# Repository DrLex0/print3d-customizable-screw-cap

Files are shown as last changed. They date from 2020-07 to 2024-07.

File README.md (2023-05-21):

# Customizable Screw Cap
*3D printable cap or lid with screw thread for tubes and round boxes*

### License
[Creative Commons - Attribution](https://creativecommons.org/licenses/by/4.0/)

### Attribution
This uses the `screw_extrude` function from “customizable round box with threaded lid” by FaberUnserzeit a.k.a. Philipp Klostermann ([Thingiverse thing:1648580](https://www.thingiverse.com/thing:1648580)).

### Gallery

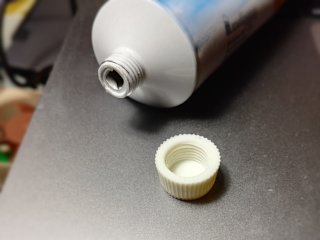
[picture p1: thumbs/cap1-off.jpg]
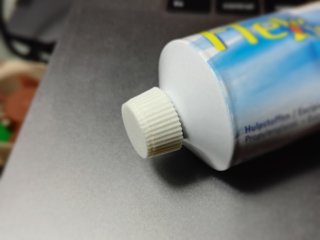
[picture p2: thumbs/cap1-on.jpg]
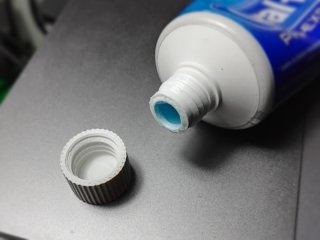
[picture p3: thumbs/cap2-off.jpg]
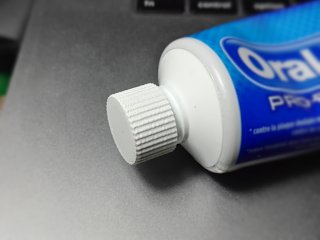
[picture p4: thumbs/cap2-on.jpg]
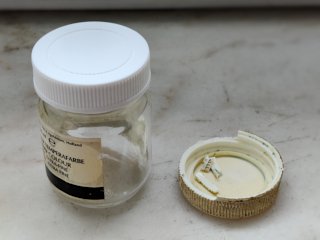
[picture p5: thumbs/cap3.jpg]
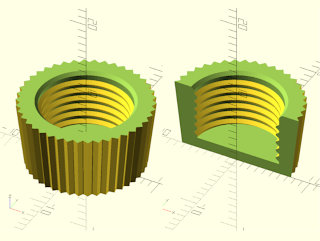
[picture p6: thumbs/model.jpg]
OpenSCAD Preview
[🔎](images/cap1-off.jpg) [🔎](images/cap1-on.jpg) [🔎](images/cap2-off.jpg) [🔎](images/cap2-on.jpg) [🔎](images/cap3.jpg) [🔎](images/model.jpg)

## Description and Instructions

This is an OpenSCAD Customizer for generating screw caps for tubes (toothpaste, gel, …), or lids for round boxes. Some possible use cases:
* You lost the cap for the tube or box,
* The original cap broke or your dog chewed on it,
* The original cap is large and bulky, and you want something more elegant to carry in a travel bag.

To generate a cap or lid for your particular needs, first do some accurate measurements on the thing the cap will need to fit on. A calliper is pretty much essential for this, although you might also get somewhere with a simple ruler and some good eyeballing. The more accurate the values, the better the chance your first printed cap will be a perfect fit and you won't need trial-and-error.

Measure these dimensions:
1. The outer diameter of the screw thread.
2. The pitch of the screw thread. It is better to measure as many turns together as possible, and then divide the measured distance by this number of turns. I usually measure with both the inside and outside prongs of the calliper to verify that I'm not making any error in the measurement.
3. The length of the threaded end that must be covered by the cap. Some tubes have a thicker ring at the base of the thread, you should not include this in the measurement.

Once you have those measurements, open the `.scad` file in [OpenSCAD](https://www.openscad.org/) and **[use the OpenSCAD Customizer](https://www.dr-lex.be/3d-printing/customizer.html)** to enter the values and generate the final STL file. Next to the above parameters, there are many other things that can be customised. The most important parameter is the spacing: if the cap is too sloppy then increase this value, if it is too tight, then lower it. For me, a spacing of 0.40 mm works well.
For certain lids it may be necessary to increase the gap between threads. The gap is expressed as a fraction of the pitch and the higher the value, the more the thread shape will be squished. High gap values may be more difficult to print cleanly.

Other parameters define the overall shape of the cap or lid. You can opt to give the cap a ribbed (knurled) outside for better grip.

### Print Settings I've used

For finer screw threads, a layer height of 0.1 mm is recommended. For coarser threads, 0.15 mm may suffice, and for big lids 0.2 mm may even be OK. The caps shown in the photos were printed with 3 perimeters. I used ABS, but in general PETG is probably the best material choice because of its toughness and resilience against chemicals. Of course PLA will also work fine in many cases.

## Example files

The `examples` folder contains some pre-rendered models of the presets.

- `Flexium` is for a metal tube of anti-inflammatory gel, and might fit similar tubes.
- `medicalBottle` fits many of the typical bottles used in medicine. The `polished` model has been tweaked in Blender to look nicer. (Should probably be used with an extra seal or wad.)
- `OralB-75ml` fits a plastic toothpaste tube and might also fit similar tubes.
- `Talens-paint-50ml` fits a small glass jar of paint. This also has a `polished` model that looks more like the original.

## License: if you want to sell prints

The OpenSCAD customizer is released under a [Creative Commons - Attribution](https://creativecommons.org/licenses/by/4.0/) license and so is every 3D model generated by it. In a nutshell, my interpretation of this license is that you can sell prints of models generated with this OpenSCAD customizer under the following conditions:

1. On webpages where you sell these models or display photos of them, or include them in a video: visibly add an *attribution* message that links back to this GitHub page, like:<br>
   “3D models generated with [Customizable Screw Cap by DrLex](https://github.com/DrLex0/print3d-customizable-screw-cap), released under *Creative Commons - Attribution* license.”
2. With every physical sold object, include a similar attribution message printed on a piece of paper that also contains the GitHub page URL. For your convenience, ready-to-print PDF files with attribution cards are provided in this repository.

If you comply with the above conditions, *you do not need to ask permission* to sell models based on this customizer. *You do not need to share profits,* the attribution is all that is required. Of course you are free to show gratitude by sharing whatever you want, for instance through the [donation options on my website](https://www.dr-lex.be/about/#contact).

## Updates

### 2020/07/02
First published.

### 2022/04/08
Added thread gap and increased limits on some parameters.

### 2023/01/05
Added option for extra unthreaded space on inside of cap, and allow bottom to be 0 to generate an open threaded tube.

### 2023/05/07
Added option for hole in the cap.

## Tags
`customizable`, `customizer`, `openscad`, `tube`, `box`, `lid`, `cap`, `thread`

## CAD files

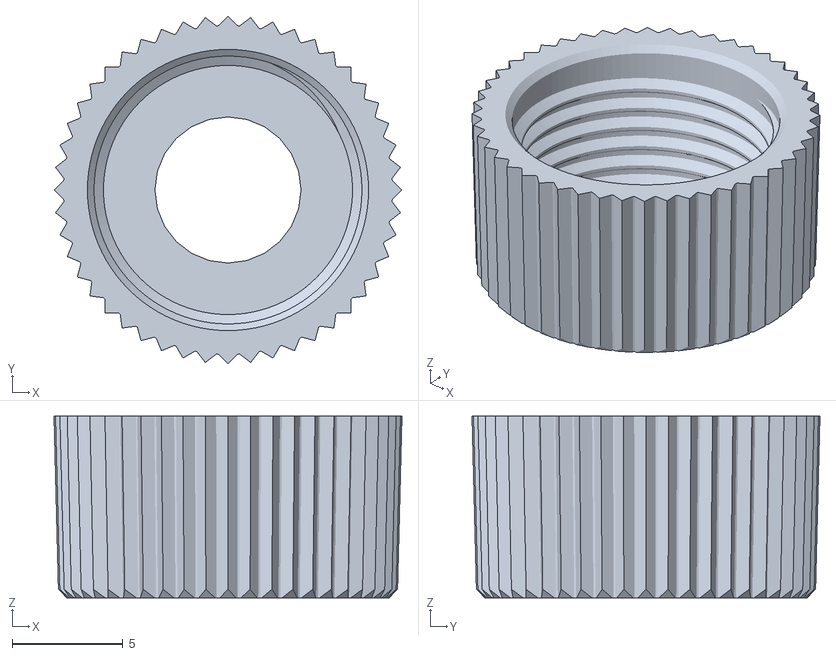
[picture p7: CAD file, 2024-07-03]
examples/ScrewCap-SKS-bicyclePump-fix.stl
15.7 x 15.7 x 8.20

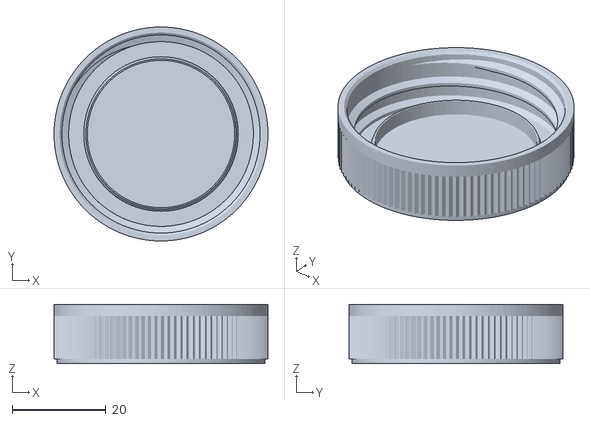
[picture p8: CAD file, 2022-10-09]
examples/ScrewCap-Talens-paint-50ml-polished.stl
45.8 x 45.7 x 12.6

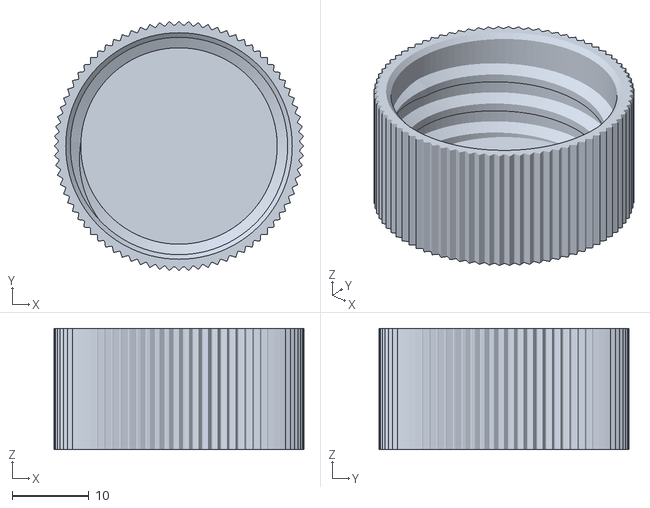
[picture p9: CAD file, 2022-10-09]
examples/ScrewCap-medicalBottle.stl
32.6 x 32.6 x 15.8

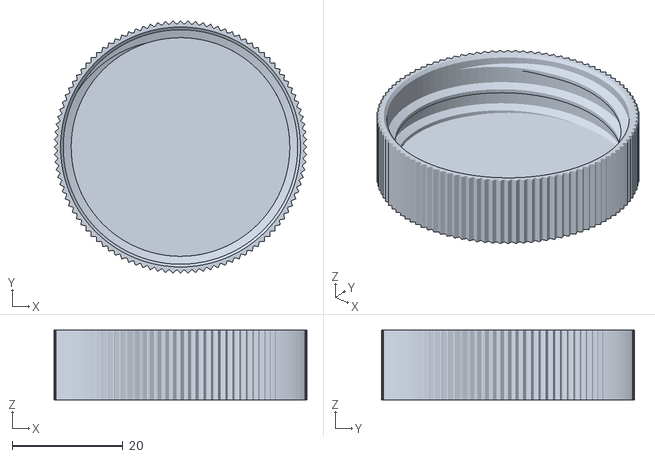
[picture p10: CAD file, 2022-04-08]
examples/ScrewCap-Talens-paint-50ml.stl
45.7 x 45.7 x 12.6

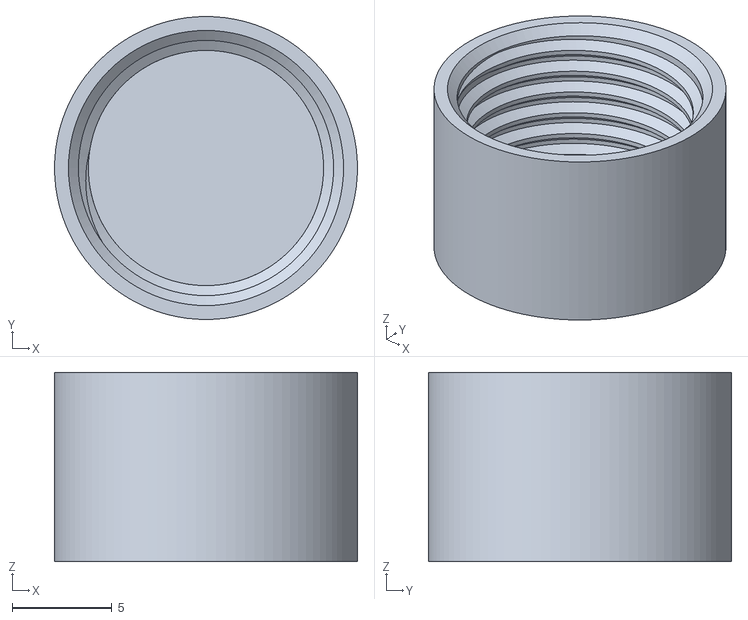
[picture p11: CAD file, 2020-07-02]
examples/ScrewCap-default.stl
15.2 x 15.2 x 9.50

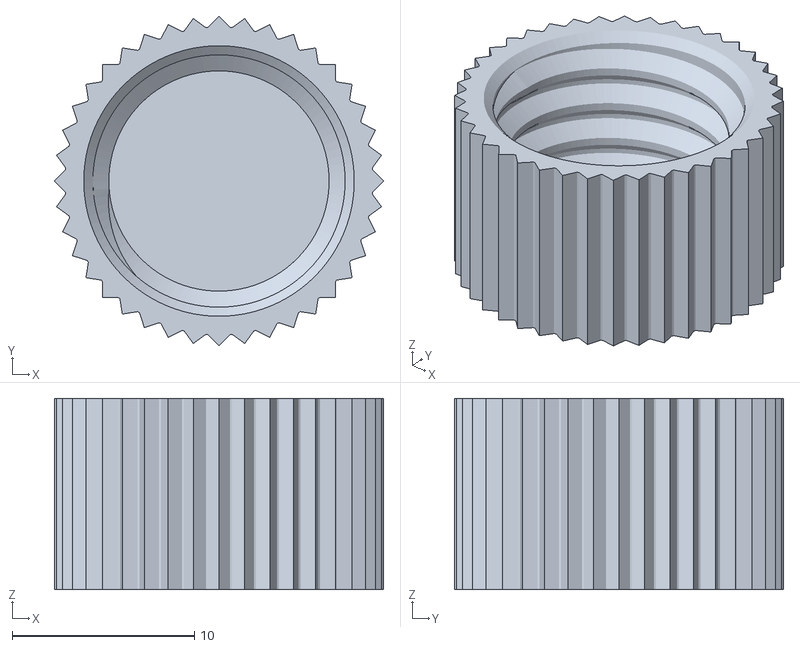
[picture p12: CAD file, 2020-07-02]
examples/ScrewCap-OralB-75ml.stl
18.1 x 18.1 x 10.5

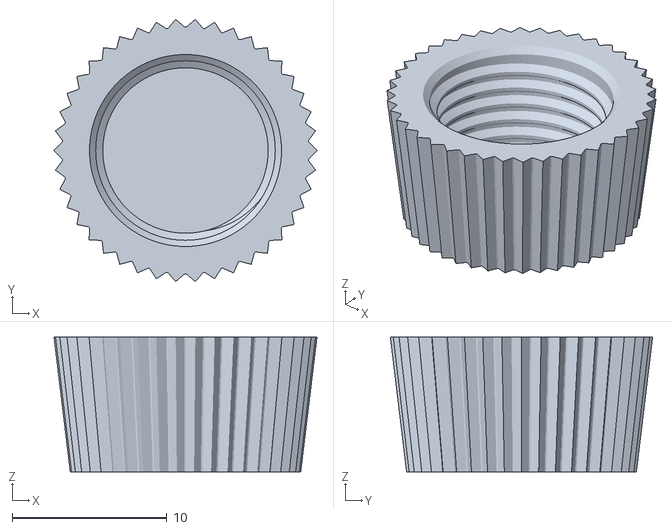
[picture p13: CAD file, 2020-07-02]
examples/ScrewCap-Flexium.stl
17.0 x 16.9 x 8.70

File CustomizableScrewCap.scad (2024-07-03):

/* Customizable screw cap generator by DrLex.
  Uses screw_extrude function from "customizable round box with threaded lid" by FaberUnserzeit (https://www.thingiverse.com/thing:1648580).
  Released under Creative Commons - Attribution license. */

/* [Screw Thread Parameters] */
// Outer diameter of the male thread on which the cap will be screwed
Thread_OD = 12.0; //[5:.05:80]
// Thread pitch (distance between each turn)
Thread_Pitch = 1.25; //[0.2:.01:5]
// The height of the thread
Thread_Length = 7; //[2:.1:30]
// Space between male thread outer diameter and cap inside diameter
Spacing = 0.4; //[0:.05:2]
// Cut away this much of the thread to make it blunt and easier going
Cut_Thread_Percent = 20; //[0:1:80]
// Extra gap between threads, expressed as fraction of the pitch. Larger gap means thinner thread.
Thread_Gap = 0; //[0:.01:0.5]

/* [Cap Geometry] */
// Thickness of the cap's wall at the closed end
Wall_Thick_1 = 1.2; //[1:.05:6]
// Thickness of the cap's wall at the open end
Wall_Thick_2 = 1.2; //[1:.05:6]
// Thickness of the cap's bottom (or top, depending on how you look at it)
Bottom = 2; //[0.0:.1:10]
// Extra unthreaded part at open end
Extra_Length = 0.5; //[0:.1:5]
// 45 degree bevel, will be clipped to smallest of Extra_Length and Wall_Thick_2
Bevel = 0.5; //[0:.05:2]
// Extra unthreaded part at closed end
Extra_Inside = 0.0; //[0:.1:30]
// For your pleasure
Ribbed = 0; //[0:no, 1:yes]
Number_of_Ribs = 32; //[16:128]
Ribs_Bevel_Top = 0; //[0:no, 1:yes]
Ribs_Bevel_Bottom = 0; //[0:no, 1:yes]

/* [Resolution] */
// Resolution of curves in steps/360°
fn = 96; //[16,32,48,64,96,128,256]

/* [Extras] */
// Use diameter > 0 to make a hole in the cap, will be clipped to wall inner diameter
Hole_dia = 0; //[0:.1:75]

// Number of segments in the hole
Hole_fn = 16; //[3:128]

/* [Visualisation] */
// Enable this to show a cross-section
Sectioned = 0; //[0:no, 1:yes]

/* [Hidden] */
tol = 0.05;
total_height = Bottom + Thread_Length + Extra_Length + Extra_Inside;
outer_dia1 = Thread_OD + 2*(Spacing + Wall_Thick_1);
outer_dia2 = Thread_OD + 2*(Spacing + Wall_Thick_2);

bevel_c = min(Bevel, Extra_Length, Wall_Thick_2);

thread_turns = Thread_Length / Thread_Pitch;
thread_thick = ((Thread_Length/thread_turns)/2);
thread_s = 1 - Thread_Gap;

cut_mittelhoehe = thread_thick*Cut_Thread_Percent/100;
cut_breite = thread_thick*(100-Cut_Thread_Percent)/100;

difference()
{
	Cap();
	if (Sectioned!=0)
	{
        rotate([0, 0, 180]) translate([-outer_dia1, 0, -tol])
			cube([outer_dia1*2, outer_dia1*2, total_height+2*tol]);
	}
}

module Cap()
{
	difference()
	{
        union() {
            translate([0,0,-2*tol])
                cylinder(h=total_height+4*tol, d1 = outer_dia1, d2 = outer_dia2, $fn=Ribbed ? Number_of_Ribs : fn);
            if(Ribbed) {
                rib_offset = [0,0,180/Number_of_Ribs];
                intersection() {
                    Ribs();
                    if(Ribs_Bevel_Top != 0) {
                        rotate(rib_offset) translate([0,0,-tol]) cylinder(h = total_height+2*tol, d1 = outer_dia2+2*total_height, d2 = outer_dia2, $fn=Number_of_Ribs);
                    }
                    if(Ribs_Bevel_Bottom != 0) {
                        rotate(rib_offset) translate([0,0,-tol]) cylinder(h = total_height+2*tol, d1 = outer_dia1, d2 = outer_dia1
                        +2*total_height, $fn=Number_of_Ribs);
                    }
                }
            }
        }
		translate([0,0,Bottom])
			cylinder(r=Thread_OD/2 + Spacing, h=Thread_Length + Extra_Length + Extra_Inside + tol, $fn=fn);
        if(bevel_c > 0) {
            translate([0, 0, total_height - bevel_c - tol]) cylinder(h=bevel_c+2*tol, r1=Thread_OD/2 + Spacing - tol, r2=Thread_OD/2 + Spacing + bevel_c + tol, $fn=fn);
        }
		translate([0,0,-10*tol])
			cylinder(r=outer_dia1, h=10*tol);
        translate([0,0,total_height])
			cylinder(r=outer_dia2, h=10*tol);

        if(Hole_dia > 0) {
            translate([0,0,-tol]) cylinder(r=min(Hole_dia/2, Thread_OD/2 + Spacing), h=2*Bottom, $fn=Hole_fn);
        }
	}

	difference()
	{
		translate([0,0, Extra_Inside + Bottom - Thread_Pitch*.33])
		{	
			screw_extrude
			(
				P = (Cut_Thread_Percent > 0) 
				?
					[
						[tol*2,-(thread_thick*thread_s-tol)],
						[-cut_breite,-cut_mittelhoehe*thread_s],
						[-cut_breite, cut_mittelhoehe*thread_s],
						[tol*2,thread_thick*thread_s-tol]
					]
				:
					[
						[tol,-(thread_thick*thread_s-tol)],
						[-thread_thick,0],
						[tol,thread_thick*thread_s-tol]
					]
				,
				r = Thread_OD / 2 + Spacing,
				p = Thread_Pitch,
				d = 360 * (thread_turns + 0),
				sr = 0,
				er = 45,
				fn = fn
			);
		}
        // Ensure thread does not stick out from top or bottom
		translate([0,0,Extra_Inside + Thread_Length + Bottom - tol])
			cylinder(r=outer_dia1, h=Thread_Pitch+tol);
		translate([0,0,-Thread_Pitch])
			cylinder(r=outer_dia1, h=Thread_Pitch+tol);
	}
}

module Ribs()
{
    angle = 360/Number_of_Ribs;
    x1 = (cos(angle/2) - sin(angle/16)) * outer_dia1/2;
    y1 = sin(angle/2) * outer_dia1/2;
    x2 = (cos(angle/2) - sin(angle/16)) * outer_dia2/2;
    y2 = sin(angle/2) * outer_dia2/2;
    for(n=[0:1:Number_of_Ribs-1]) {
        rotate([0,0,n*angle]) {
            polyhedron([
                [x1, y1, -tol], [x1, -y1, -tol], [x1+y1, 0, -tol],
                [x2, y2, total_height+tol], [x2, -y2, total_height+tol], [x2+y2, 0, total_height+tol]
            ],
            [[0, 1, 2], [0, 3, 4, 1], [0, 2, 5, 3], [1, 4, 5, 2], [3, 5, 4]], convexity=4);
        }
    }
}

/**
 * screw_extrude(P, r, p, d, sr, er, fn)
	by Philipp Klostermann
	
	screw_rotate rotates polygon P 
	with the radius r 
	with increasing height by p mm per turn 
	with a rotation angle of d degrees
	with a starting-ramp of sr degrees length
	with an ending-ramp of er degrees length
	in fn steps per turn.
	
	the points of P must be defined in clockwise direction looking from the outside.
	r must be bigger than the smallest negative X-coordinate in P.
	sr+er <= d
**/

module screw_extrude(P, r, p, d, sr, er, fn)
{
	anz_pt = len(P);
	steps = round(d * fn / 360);
	mm_per_deg = p / 360;
	points_per_side = len(P);
	echo ("steps: ", steps, " mm_per_deg: ", mm_per_deg);
	
	VL = [ [ r, 0, 0] ];
	PL = [ for (i=[0:1:anz_pt-1]) [ 0, 1+i,1+((i+1)%anz_pt)] ];
	V = [
		for(n=[1:1:steps-1])
			let 
			(
				w1 = n * d / steps,
				h1 = mm_per_deg * w1,
				s1 = sin(w1),
				c1 = cos(w1),
				faktor = (w1 < sr)
				?
					(w1 / sr)
				:
					(
						(w1 > (d - er))
						?
							1 - ((w1-(d-er)) / er)
						:
							1
					)
			)
			for (pt=P)
			[
				r * c1 + pt[0] * c1 * faktor, 
				r * s1 + pt[0] * s1 * faktor, 
				h1 + pt[1] * faktor 
			]
	];
	P1 = [
		for(n=[0:1:steps-3])
			for (i=[0:1:anz_pt-1]) 
			[
				1+(n*anz_pt)+i,
				1+(n*anz_pt)+anz_pt+i,
				1+(n*anz_pt)+anz_pt+(i+1)%anz_pt
			] 
			
		
	];
	P2 = 
	[
		for(n=[0:1:steps-3])
			 for (i=[0:1:anz_pt-1]) 
				[
					1+(n*anz_pt)+i,
					1+(n*anz_pt)+anz_pt+(i+1)%anz_pt,
					1+(n*anz_pt)+(i+1)%anz_pt,
				] 
			
		
	];

	VR = [ [ r * cos(d), r * sin(d), mm_per_deg * d ] ];
	PR = 
	[
		for (i=[0:1:anz_pt-1]) 
		[
			1+(steps-1)*anz_pt,
			1+(steps-2)*anz_pt+((i+1)%anz_pt),
			1+(steps-2)*anz_pt+i
		]
	];
			
	VG=concat(VL,V,VR);
	PG=concat(PL,P1,P2,PR);
	convex = round(d/45)+4;
	echo ("convexity = round(d/180)+4 = ", convex);
	polyhedron(VG,PG,convexity = convex);
}

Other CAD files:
examples/ScrewCap-medicalBottle-polished.stl

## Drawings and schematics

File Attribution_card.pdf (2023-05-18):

# Customizable Screw Cap by DrLex

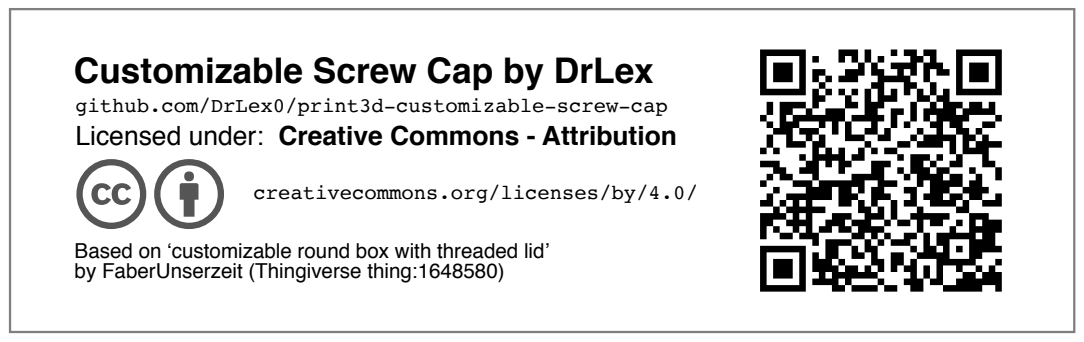
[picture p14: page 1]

github.com/DrLex0/print3d-customizable-screw-cap
Licensed under: Creative Commons - Attribution

creativecommons.org/licenses/by/4.0/

Based on ‘customizable round box with threaded lid’
by FaberUnserzeit (Thingiverse thing:1648580)

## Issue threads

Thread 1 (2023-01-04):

Extra length at closed end

SahajJain01, 2023-01-04:
Is it possible to add extra length at closed end? Trying to make a cap for nozzle tubes which have a nozzle tip and then a threaded section.

DrLex0, 2023-01-05:
Option added. Thanks for the suggestion!

Closed 2023-01-05.

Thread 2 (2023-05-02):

Feature Request: option to add holes through the lid

jrishel, 2023-05-02:
I'd love a parameter to add holes in the lid, either to fit a small tube/straw through or many small holes to make a shaker.  I've played around with trying to implement this but haven't got anything working yet. Just sharing the idea in case someone else wants to tackle that before have something working.

DrLex0, 2023-05-07:
There is now an option to add one hole. Implementing “many small holes” is not straightforward, there are several ways to do this like a simple regular grid, a spiral, or concentric circles. If someone else can make an elegant solution for this, they are free to create a pull request.

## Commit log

2022-04-08 Add thread gap; increase parameter range; add new example
    [CustomizableScrewCap.scad, ScrewCap-Talens-paint-50ml.stl]
2022-10-09 Add another example, and description of examples
    [ScrewCap-Talens-paint-50ml-polished.stl, ScrewCap-medicalBottle-polished.stl, ScrewCap-medicalBottle.stl]
2023-01-05 Add extra space at closed end (issue #1)
    and also allow bottom to be 0 for an open tube.
    [CustomizableScrewCap.scad]
2023-05-07 Add optional hole to cap (partial fix for issue #2)
    [CustomizableScrewCap.scad]
2023-05-18 Add attribution info and ready-to-print cards
2024-07-03 Add option to bevel the rib edges.
    Add example for ready-to-use spare part for old SKS 90° angle bicycle pump.
    [CustomizableScrewCap.scad, ScrewCap-SKS-bicyclePump-fix.stl]
